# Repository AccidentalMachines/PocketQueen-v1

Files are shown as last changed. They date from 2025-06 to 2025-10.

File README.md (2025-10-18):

# Pocket Queen 1.0

**Pocket Queen** is a modern 3D-printed metronome for drummers, featuring both audible and visual tempo cues. It’s designed to sit on a table or mount anywhere on a drum kit using a standard 1/4-20 clamp.

---

## ⚠️ WARNING — Work in Progress
Pocket Queen v1.0 is still a work in progress.  
The current hardware design **does not include an onboard charging circuit** for the lithium-ion battery.  
To recharge the battery, the unit must be **disassembled and the battery removed** for charging with an **Adafruit Micro-Lipo Charger for LiPoly batteries (USB Type-C)**.  

> Note: The Micro-USB port on the Pocket Queen does **not** recharge the battery — it only provides USB data/power to the Adafruit Circuit Playground Bluefruit board.  This critical design limitation **will be addressed in the next hardware revision.**

---

### Features
- Audible metronome click + LED ring for visual cues  
- Tabletop or clamp-mountable design  
- Compact and rugged — made for drummers, by a drummer  
- 3D-printable enclosure and open files for DIYers  

---

### What's in this repo
- `/STL` – 3D-printable files for the enclosure  
- `/Firmware` – Firmware designed for the Adafruit Circuit Playground Bluefruit
- `/BOM.csv` – Bill of Materials with links  
- `/Instructions.pdf` – Assembly and usage guide  

---

### 🔧 Build Your Own
Want to build Pocket Queen yourself?

- 🛠💾 [Hardware, Firmware, & Assembly Guide](https://github.com/AccidentalMachines/PocketQueen-v1/)
- 📘 [More Info at accidentalmachines.com](https://accidentalmachines.com)

Files are free for personal use.  

---

## License

This project is licensed under the Creative Commons Attribution-NonCommercial 4.0 International License.

You're free to use, remix, and build upon this work for personal or educational use.  
Commercial use is not permitted.

Copyright © 2025 Baret Kilbacak  
Learn more: [https://creativecommons.org/licenses/by-nc/4.0/](https://creativecommons.org/licenses/by-nc/4.0/)

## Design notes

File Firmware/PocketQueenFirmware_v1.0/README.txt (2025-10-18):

Thank you for downloading the Pocket Queen v1.0 firmware!

This Arduino sketch (PocketQueenFirmware_v1.ino) powers the Pocket Queen v1.0 metronome — a modular timing tool for drummers, featuring LED ring cues, click output, and onboard controls. It’s designed to run on the Adafruit Circuit Playground board.

📂 Included Files:
- PocketQueenFirmware_v1.ino — the main firmware sketch
- LEDMatSim.cpp — LED simulation logic
- volume_bitmap.c, swg_bitmap.c, bpm_bitmap.c — icon bitmaps for OLED display

📌 Requirements:
- Adafruit Circuit Playground
- 0.96" OLED I2C Display (128x64)
- 3.7V LiPo battery
- Arduino IDE + Adafruit libraries

🔧 Setup:
1. Open `PocketQueenFirmware_v1.ino` in the Arduino IDE
2. Install required libraries (Adafruit Circuit Playground, Adafruit GFX, SSD1306)
3. Upload the code to your Circuit Playground Bluefruit board
4. Connect to your hardware and start drumming

📎 Full hardware files, build guide, and documentation:
→ https://accidentalmachines.com

Questions? Feedback? Want to share your build?
Contact: ekilbacak [dot] com

Enjoy — and stay on time.

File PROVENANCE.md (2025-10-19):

# Provenance

- **Project:** Pocket Queen v1.0  
- **On-chain proof (Zora):** https://zora.co/coin/base:0x53159797a133b0477d252f8068a53515d0940b79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  
- **Intent:** Authorship timestamping only; not a sales channel.

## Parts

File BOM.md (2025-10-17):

## Bill of Materials – Pocket Queen v1

| Item | Description | Quantity | Source/Link | Notes |
|---|---|---|---|---|
| Circuit Board | Adafruit Circuit Playground Express | 1 | [Link](https://www.adafruit.com/product/3333) | Main controller with LEDs, buttons, and speaker |
| Display | Weewooday 0.96" OLED Module 128x64 I2C | 1 | [Link](https://www.amazon.com/dp/B08N6W9Z3G) | OLED screen for BPM display |
| Battery | Adafruit Lithium Ion Polymer Battery - 3.7V 500mAh | 1 | [Link](https://www.adafruit.com/product/1578) | Powers the CPX via JST connector |
| Main Mounting Insert | Rockler Low-Profile Threaded Insert (#39631) | 1 | [Link](https://www.rockler.com/low-profile-threaded-inserts-select-size) | For mounting to drum kit with 1/4-20 hardware |
| Internal Inserts | M3×8×5mm Threaded Inserts (Ktehloy) | 2 | [Link](https://www.amazon.com/dp/B0CLKDPN65) | Used for internal part fastening |
| Internal Inserts | M2.5×2.5×3.5mm Threaded Inserts | 12 | [Link](https://www.amazon.com/dp/B0CLKDPN65) | Used for smaller structural connections |
| Fasteners | Assorted screws for M2.5 & M3 inserts | Varies | [Link](https://www.amazon.com/dp/B075C6C4YR) | To mate with threaded inserts |
| Power Switch | Chanzon SPDT Mini Micro Slide Switch (SS12F15) | 1 | [Link](https://www.amazon.com/dp/B09R3Y6MMN/) | Used for on/off power control |
| Ring Terminals | TE 160344-2 Ring Terminal, M3, 15-20AWG | 4 | [Link](https://www.digikey.com/en/products/detail/te-connectivity-amp-connectors/160344-2/2285572) | For clean, secure power and signal connections |
| Wiring Kit | Fermerry 20 AWG Silicone Hookup Wire (6 colors, 50ft each) | 1 set | [Link](https://www.amazon.com/dp/B08D6TNJHS) | Flexible tinned copper wire for internal wiring |

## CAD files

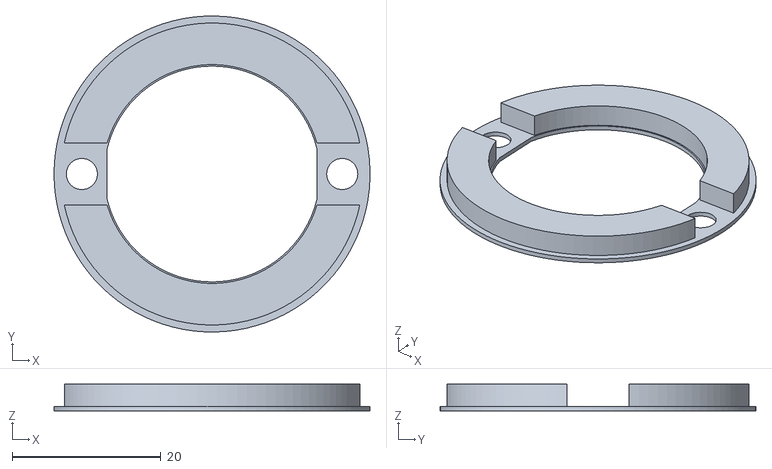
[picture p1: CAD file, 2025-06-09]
STL/PocketQueen-v1-Diffuser.stl
42.5 x 42.6 x 3.60

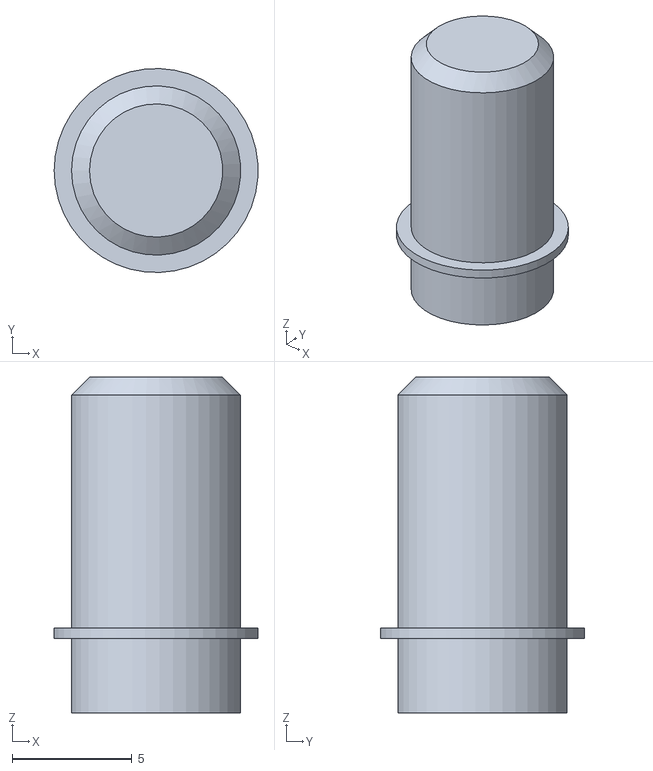
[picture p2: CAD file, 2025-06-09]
STL/PocketQueen-v1-Button.stl
8.49 x 8.49 x 14.0

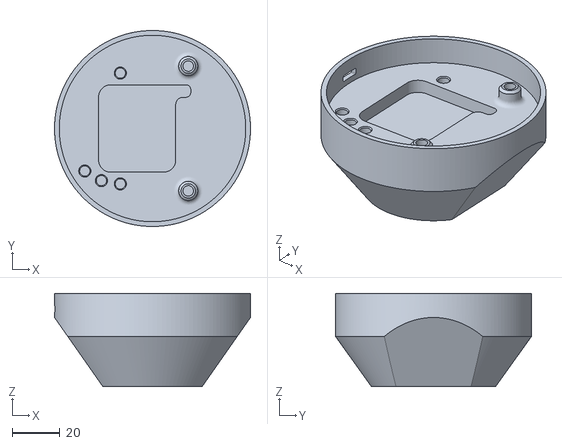
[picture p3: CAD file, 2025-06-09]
STL/PocketQueen-v1-Body.stl
82.0 x 82.0 x 39.0

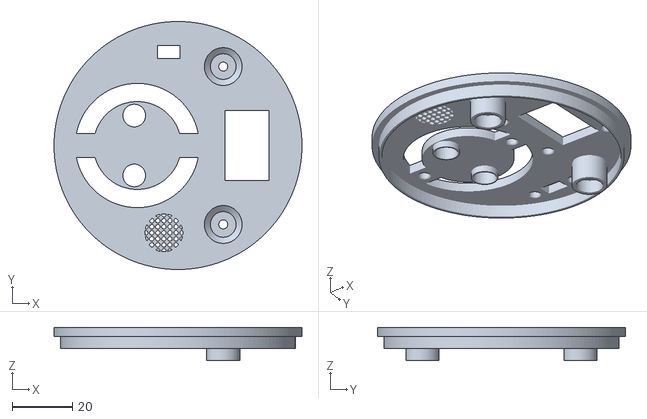
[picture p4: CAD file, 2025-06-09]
STL/PocketQueen-v1-Face-Cover.stl
82.0 x 82.0 x 11.0

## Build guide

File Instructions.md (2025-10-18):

# Pocket Queen v1 – Assembly Instructions

These instructions will walk you through assembling your own Pocket Queen v1 metronome.

---

## 🖨️ Step 1: 3D Printing the Parts

Print the following STL files using your preferred 3D printer (tested on FlashForge Adventurer 4):

- `PocketQueen-v1-Body.stl`
- `PocketQueen-v1-Button.stl`
- `PocketQueen-v1-Diffuser.stl`
- `PocketQueen-v1-Face-Cover.stl`

All files are optimized for standard FDM printing and should work on most hobbyist printers.

---

## 🔩 Step 2: Install Threaded Inserts

Use a soldering iron or insert-setting tool to heat-set the threaded inserts into the appropriate holes in the 3D printed parts:

- M3 and M2.5 inserts go into their designated slots for mounting internal components.

---

## 🔧 Step 3: Wiring and Soldering

1. **Crimp Wires:** Cut and crimp wire leads for connections using ring terminals.
2. **OLED Display:** Solder the wire leads to the pins of the OLED display (I2C interface).
3. **Power Switch:**
   - Cut the positive (red) wire between the battery and its JST connector.
   - Solder the SPDT switch inline to allow power cutoff to the Circuit Playground.

---

## ⚡ Step 4: Final Assembly

1. Mount the **Circuit Playground Bluefruit** inside the main body using screws.
2. Connect the **OLED display** and secure it behind the face cover.
3. Plug in the **battery** via the JST connector.
4. Fit all parts together and secure with screws through the pre-threaded inserts.
5. Snap on the diffuser and press-fit the button into place.

---

## ✅ Final Check

- Flash the firmware from this repo to the Circuit Playground Bluefruit.
- Toggle the switch and confirm LED ring + click sound.
- Secure with clamp or place on table — you're ready to drum.

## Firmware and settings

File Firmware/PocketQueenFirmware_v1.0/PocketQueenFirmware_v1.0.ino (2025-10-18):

// Arduino standard library
#include <Arduino.h>

// Board preprocessor defintions
#ifdef ARDUINO_NRF52840_CIRCUITPLAY
#define ADAFRUIT_CIRCUITPLAYGROUND
#define NRF52_TIMER2
#define AUDIO_CPU
#else // ADAFRUIT_CIRCUITPLAYGROUND_BLUEFRUIT
#ifdef ADAFRUIT_CIRCUITPLAYGROUND_M0
#define ADAFRUIT_CIRCUITPLAYGROUND
#define SAMD_TC4
#define AUDIO_CPU
#else // Not Circuit Playground Express
#if !defined(ARDUINO_NRF52840_CIRCUITPLAY) and !defined(ADAFRUIT_CIRCUITPLAYGROUND_M0)
#define RTOS
#define AUDIO_I2S
#endif 
#endif // ADAFRUIT_CIRCUITPLAYGROUND_M0 
#endif // ADAFRUIT_CIRCUITPLAYGROUND_BLUEFRUIT
#ifdef ADAFRUIT_CIRCUITPLAYGROUND
#define TWO_BUTTONS
#define SPDT_SWITCH
#endif // ADAFRUIT_CIRCUITPLAYGROUND

// Firmware version
#define VERSION F("0.3")

// For USB
#ifdef ARDUINO_NRF52840_CIRCUITPLAY
// #define USB_DISABLE
#define USB_SUSPEND_KEEP_HFCLK
#endif // ARDUINO_NRF52840_CIRCUITPLAY

// For Clock
#ifdef ARDUINO_NRF52840_CIRCUITPLAY
#define ENABLE_HFCLK // Enables high frequency clock when metronome is ticking, required to keep high accuracy when powered by battery
// #define FORCE_HFCLK // Not optimal, but forces high frequency clock every loop to prevent USB suspend event from using lower accuracy internal RC oscillator
#define LFCLK_CALIBRATION_TIME 16 // Calibrate for 4 seconds (16 * 0.25 seconds)
#endif // ARDUINO_NRF52840_CIRCUITPLAY

// For Serial
#ifndef USB_DISABLE
// #define SERIAL_DEBUG
#define SERIAL_DEBUG_WAIT_INIT
#ifdef SERIAL_DEBUG
#define BAUD_RATE 115200
#ifdef ARDUINO_NRF52840_CIRCUITPLAY
#include <Adafruit_TinyUSB.h>
#endif // ARDUINO_NRF52840_CIRCUITPLAY
#endif // SERIAL_DEBUG
#endif // USB_DISABLE

// For Sound
#ifdef RTOS
#include <freertos/FreeRTOS.h>
#include <freertos/task.h>
#endif // RTOS
#ifdef AUDIO_I2S
#include <Audio.h>
#include <SPIFFS.h>
#endif // AUDIO_I2S

// For Display
#ifdef ADAFRUIT_CIRCUITPLAYGROUND
#include <Wire.h>
#else
#include <SPI.h>
#endif // ADAFRUIT_CIRCUITPLAYGROUND
#include <Adafruit_GFX.h>
#include <Adafruit_SSD1306.h>
// Origin offset in pixels
#define ORIGIN_OFFSET_X 0
#define ORIGIN_OFFSET_Y 8
#define ORIGIN_OFFSET_DOT_X ORIGIN_OFFSET_X / 4
#define ORIGIN_OFFSET_DOT_Y ORIGIN_OFFSET_Y / 4
// Dot matrix coordinates
#define TEMPO_DOTS_X 8 + ORIGIN_OFFSET_DOT_X
#define TEMPO_DOTS_Y 0 + ORIGIN_OFFSET_DOT_Y
#define UPPER_TIME_SIGNATURE_X 0 + ORIGIN_OFFSET_DOT_X
#define UPPER_TIME_SIGNATURE_Y 0 + ORIGIN_OFFSET_DOT_Y
#define LOWER_TIME_SIGNATURE_X 0 + ORIGIN_OFFSET_DOT_X
#define LOWER_TIME_SIGNATURE_Y 7 + ORIGIN_OFFSET_DOT_Y
// Bitmaps
#define BPM_BITMAP_X 106 + ORIGIN_OFFSET_X 
#define BPM_BITMAP_Y 16 + ORIGIN_OFFSET_Y
#include "bpm_bitmap.c"
#define SWG_BITMAP_X 104 + ORIGIN_OFFSET_X
#define SWG_BITMAP_Y 16 + ORIGIN_OFFSET_Y
#include "swg_bitmap.c"
#define VOLUME_BITMAP_X 36 + ORIGIN_OFFSET_X
#define VOLUME_BITMAP_Y 43 + ORIGIN_OFFSET_Y
#define VOLUME_DOTS_LENGTH 15
#define VOLUME_DOTS_START_X 10 + ORIGIN_OFFSET_X / 4
#define VOLUME_DOTS_Y 11 + ORIGIN_OFFSET_Y / 4
#include "volume_bitmap.c"

// For NeoPixel
#define NEOPIXEL
#ifdef NEOPIXEL
#include <Adafruit_NeoPixel.h>
#endif //NEOPIXEL

// For Input

// Serial control commands
#ifdef SERIAL_DEBUG
#define SERIAL_CONTROL
#ifdef SERIAL_CONTROL
#define SERIAL_CONTROL_PRESS 'p'
#define SERIAL_CONTROL_LONG_PRESS 'l'
#define SERIAL_CONTROL_TURN_CW 't'
#define SERIAL_CONTROL_TURN_CCW 'r'
#define SERIAL_CONTROL_DEBUG 'd'
#define SERIAL_CONTROL_ETC 'e'
#define SERIAL_CONTROL_SPECIAL 's'
#endif // SERIAL_CONTROL
#endif // SERIAL_DEBUG

// Buttons and switch
#ifdef TWO_BUTTONS
//#define PRESSED_LED // Use builtin LED to indicate short press
#define BUTTON_A 5
#define BUTTON_B 4
#define BUTTON_READ_PERIOD 150UL
#define BUTTON_DOUBLE_PRESS_PERIOD 300UL // Must be multiple of read period for accuracy
#endif // TWO_BUTTONS
#ifdef SPDT_SWITCH
#define SWITCH_A 7
#endif // SPDT_SWITCH

// VCC and temperature debugging
//#define VCC_AND_TEMP_DEBUG

// Rotary encoder
// Pin A, Pin B, Button Pin
//#define ROTARY_ENCODER
#ifdef ROTARY_ENCODER
#include <SimpleRotary.h>
#define ROTARY_A 14
#define ROTARY_B 15
#define ROTARY_BUTTON 2
SimpleRotary rotary(ROTARY_A, ROTARY_B, ROTARY_BUTTON);
#endif // ROTARY_ENCODER

// Input
byte turn;
byte pressed;
byte long_pressed;
// Direction
#define CW 1
#define CCW 2

// LEDs
// #define SETUP_LED // Turns on LED_BUILTIN during initialization to indicate setup time
// #define HFCLK_SRC_LED // Sets LED_BUILTIN to the value of the SRC bit of HFCLKSTAT, indicating clock source
#ifdef NEOPIXEL
#define SEIZURE_PREVENTION
//#define SEIZURE_PREVENTION_TESTING A2
#ifdef ADAFRUIT_CIRCUITPLAYGROUND
#define NEOPIXEL_PIN 8
#define NEOPIXEL_COUNT 10
#define NEOPIXEL_ROTATE
#define NEOPIXEL_COLOR
#define NEOPIXEL_WHITE
#else // Not Circuit Playground board
#define NEOPIXEL_PIN 22
#define NEOPIXEL_COUNT 16
#endif // ADAFRUIT_CIRCUITPLAYGROUND
Adafruit_NeoPixel pixels(NEOPIXEL_COUNT, NEOPIXEL_PIN, NEO_GRB + NEO_KHZ800);
#if defined(NEOPIXEL_COLOR) && defined(NEOPIXEL_WHITE)
#define NEOPIXEL_COLOR_COUNT 6
uint8_t neopixel_color_offset = 0;
#endif // NEOPIXEL_COLOR && NEOPIXEL_WHITE
#endif // NEOPIXEL

// Display
#define OLED
#define LED_MATRIX_SIM
#ifdef OLED
#define SSD1306
#ifdef SSD1306
#define OLED_INIT_DELAY  100
#define OLED_WIDTH 128
#define OLED_HEIGHT 64
#define OLED_ROTATION 0 // 90 degree intervals
#ifdef ADAFRUIT_CIRCUITPLAYGROUND
#define OLED_I2C
#ifdef OLED_I2C
#define OLED_ADDR 0x3C
#define OLED_RESET  -1
#define OLED_SCK    A4
#define OLED_SDA    A5
Adafruit_SSD1306 display(OLED_WIDTH, OLED_HEIGHT, &Wire, OLED_RESET);
#endif // OLED_I2C
#else // ESP32
#define OLED_SPI
#ifdef OLED_SPI
#define OLED_MOSI   23
#define OLED_CLK    18
#define OLED_DC     17
#define OLED_CS     19
#define OLED_RESET  5
Adafruit_SSD1306 display(OLED_WIDTH, OLED_HEIGHT,
    OLED_MOSI, OLED_CLK, OLED_DC, OLED_RESET, OLED_CS);
#endif // OLED_SPI
#endif // ADAFRUIT_CIRCUITPLAYGROUND
#endif // SSD1306
#ifdef LED_MATRIX_SIM
#include "LEDMatSim.cpp"
LEDMatSim ledmatsim(display, 32, 16);

// LED Matrix simulation dot configuration demo
typedef uint8_t bits_t;
bits_t new_dots_wh = 4;
bits_t new_dots[] = {
    0b00000000,
    0b00100000,
    0b00000000,
};

#endif // LED_MATRIX_SIM
#endif // OLED

// Audio constants
#if defined(AUDIO_DAC) || defined(AUDIO_CPU)
#define AUDIO_PIN A0
#define AUDIO_DUR 10
#define AUDIO_FREQ_A4 440.0
#define AUDIO_FREQ_E5 659.25
#define AUDIO_FREQ_A5 880.0
#ifdef ADAFRUIT_CIRCUITPLAYGROUND_M0
#define TONE_RESOLUTION 10
#else
#define TONE_RESOLUTION 8
#endif // ADAFRUIT_CIRCUITPLAYGROUND_M0
#define POWER_OF_TWO(x) (2 ^ x)
#ifdef AUDIO_DAC
#define AUDIO_ANALOG
#else
#define AUDIO_DIGITAL
#endif // AUDIO_DAC
//#define TEST_TONES
#else
#define AUDIO_I2S
#define I2S_LRC 26
#define I2S_DOUT 25
#define I2S_BCLK 27
#endif // AUDIO_DAC

// Audio variables and functions
volatile uint8_t counter = 0;
#if defined(AUDIO_DAC) || defined(AUDIO_CPU)
double audio_freq[] = {AUDIO_FREQ_A4, AUDIO_FREQ_E5, AUDIO_FREQ_A5};
unsigned long previous_tone_time = 0;
#endif // AUDIO_DAC or AUDIO_CPU
#ifdef AUDIO_I2S
Audio audio;
char *audio_files[] = {"/loo.mp3", "/loo_old.mp3" "/hii.mp3"};   
#endif // AUDIO_I2S
#ifdef RTOS
TaskHandle_t audio_task_handle = NULL;
TaskHandle_t audio_task_handle2 = NULL;
#endif // RTOS
#if defined(SAMD_TC4) || defined(NRF52_TIMER2)
volatile unsigned long interval = 1000000UL; // Default to 1 second
#endif // SAMD_TC4 or NRF52_TIMER2

// METRONOME SETTINGS
#define MAX_VOL 100
#define MIN_VOL 0

#define MAX_BEAT 8
#define MIN_BEAT 1

#define MAX_TEMPO 200
#define MIN_TEMPO 20
                
#define MAX_RHYTHM 8
#define MIN_RHYTHM 1

#define MAX_SWING 100
#define MIN_SWING 0

// Metronome settings
bool metronome_on = false;
uint8_t volume_val = 100;
uint8_t beat_val = 4;
uint8_t tempo_val = 120;
uint8_t rhy_val = 1;
uint8_t swing_val = 50;

// Menu constants
#define SELECT_BLINK_TIME 400UL
#define MODIFY_BLINK_TIME 100UL
enum selection // In menu order
{
#ifdef LED_MATRIX_SIM
#define SELECTION_COUNT 5
    SELECT_TEMPO,
    SELECT_SWING,
    SELECT_VOLUME,
    SELECT_RHYTHM,
    SELECT_BEAT
#else // !LED_MATRIX_SIM
#define SELECTION_COUNT 4
    SELECT_VOLUME,
    SELECT_BEAT,
    SELECT_TEMPO,
    SELECT_RHYTHM
#endif
};

// Menu variables
bool select_flag = false;
bool modify_flag = false;
uint8_t select_line = 0;
bool blink_flag = false;
unsigned long last_blink = 0;

#if defined(AUDIO_DAC) || defined(AUDIO_CPU)
// Manual tone generation to su
void volumeTone(uint32_t frequency, uint32_t duration, uint8_t volume)
{
    uint32_t halfPeriod = 1000000UL / frequency / 2;
    #ifdef AUDIO_ANALOG
    volume = map(volume, 0, 100, 0, POWER_OF_TWO(TONE_RESOLUTION));
    #endif // AUDIO_ANALOG

    for (uint32_t i = 0; i < frequency * duration / 1000; i++)
    {
        #ifdef AUDIO_ANALOG
        analogWrite(AUDIO_PIN, volume);
        #endif
        #ifdef AUDIO_DIGITAL
        digitalWrite(AUDIO_PIN, HIGH);
        #endif
        delayMicroseconds(halfPeriod);
        #ifdef AUDIO_ANALOG
        analogWrite(AUDIO_PIN, 0);
        #endif
        #ifdef AUDIO_DIGITAL
        digitalWrite(AUDIO_PIN, LOW);
        #endif
        delayMicroseconds(halfPeriod);
    }
}
#endif // AUDIO_DAC or AUDIO_CPU

#ifdef AUDIO_PWM
void volumeTone(uint32_t frequency, uint32_t duration, uint8_t volume)
{

}
#endif

void playAudio(int audio_index)
{
    #if defined(AUDIO_DAC) || defined(AUDIO_CPU)
    volumeTone(audio_freq[audio_index], AUDIO_DUR, volume_val);
    #endif // AUDIO_DAC or AUDIO_CPU
    previous_tone_time = micros();

    #ifdef AUDIO_I2S
    audio.connecttoFS(SPIFFS, audio_files[audio_index]);
    while (audio.isRunning()) 
    {
        audio.loop();
    }
    #endif // AUDIO_I2S
}

unsigned long calculateTiming()
{
    // Calculate period between metronome ticks based on tempo and rhythm division
    unsigned long period = tempo_val != 0 ? 
        60 * 1000000UL / (tempo_val * rhy_val) : 
        50UL;

    // Adjust period based on swing percentage if not 50%
    return swing_val == 50 ? 
        period : 
        period * (counter % 2 ?
            150 - swing_val : 
            swing_val + 50) 
            / 100.0;
}

void audioTask()
{
    #ifdef RTOS
    TickType_t xLastWakeTime, xFrequency;
    xLastWakeTime = xTaskGetTickCount();
    for (;;)
    #endif // RTOS
    {
        #ifdef RTOS
        vTaskDelayUntil(&xLastWakeTime, xFrequency);
        #endif // RTOS
        #if defined(SAMD_TC4) || defined(NRF52_TIMER2)
        unsigned long timing = calculateTiming();
        #endif // SAMD_TC4 or NRF52_TIMER2
        #ifdef SAMD_TC4
        if(timing != interval) setTC4(timing);
        #else
        #ifdef NRF52_TIMER2
        if(timing != interval) setTIMER2(timing);
        #endif // NRF52_TIMER2
        #endif // SAMD_TC4

        // Play audio
        #if !defined(NRF52_TIMER2) && !defined(SAMD_TC4)
        if(metronome_on)
        #endif // NRF52_TIMER2 && SAMD_TC4
        {
            #ifdef AUDIO_I2S
            audio.setVolume(volume_val);
            #endif

            #if defined(AUDIO_I2S) || defined(AUDIO_DAC) 
            if(
                #ifdef AUDIO_I2S
                audio.isRunning() &&
                #endif // AUDIO_I2S
                #ifdef AUDIO_DAC
                // Check to ensure DAC is done generating audio
                micros() - previous_tone_time >= AUDIO_DUR * 1000
                #endif // AUDIO_DAC
            ) 
            #endif // AUDIO_I2S || AUDIO_DAC
            {
                // Increment and wrap counter
                counter ++;
                counter %= beat_val * rhy_val;

                // Play audio if volume is not 0
                // First beat of measure is sound 2, other beats are sound 1, and subdivisions are sound 0
                if(volume_val)
                    playAudio(
                        counter == 0 ? 2
                        : counter % rhy_val == 0 ? 1
                        : 0);
            }
        }
    }
}

#ifdef SAMD_TC4
void configureTC4()
{
    // Enable shared generic clock for TC4 and TC5
    GCLK->CLKCTRL.reg = GCLK_CLKCTRL_CLKEN |
                        GCLK_CLKCTRL_GEN_GCLK0 |
                        GCLK_CLKCTRL_ID_TC4_TC5;
    while (GCLK->STATUS.bit.SYNCBUSY);
    
    // Reset timer/counter 4
    TC4->COUNT32.CTRLA.reg = TC_CTRLA_SWRST;
    // Wait for syncronization
    while (TC4->COUNT32.STATUS.bit.SYNCBUSY);
    while (TC4->COUNT32.CTRLA.bit.SWRST);

    // Set 32 bit counter and match frequency modes, disable prescaler division, and enables timer counter to start
    TC4->COUNT32.CTRLA.reg |= TC_CTRLA_MODE_COUNT32 |
                              TC_CTRLA_WAVEGEN_MFRQ | TC_CTRLA_PRESCALER_DIV1 | 
                              TC_CTRLA_ENABLE;
    while (TC4->COUNT32.STATUS.bit.SYNCBUSY);

    // Set timer compare capture register
    setTC4(interval);

    // Enable the TC4 interrupt request
    TC4->COUNT32.INTENSET.bit.MC0 = 1;
    // Enable TC4 interrupt
    NVIC_EnableIRQ(TC4_IRQn);
}

void setTC4(unsigned long new_interval) 
{
    interval = new_interval;
    TC4->COUNT32.CC[0].reg = 48UL * interval;
    while (TC4->COUNT32.STATUS.bit.SYNCBUSY);
}

inline void toggleTC4(bool enable)
{
    TC4->COUNT32.CTRLA.bit.ENABLE = enable;
    while(TC4->COUNT32.STATUS.bit.SYNCBUSY);
}

inline void triggerTC4()
{
    TC4->COUNT32.COUNT.reg = TC4->COUNT32.CC[0].reg; 
    while(TC4->COUNT32.STATUS.bit.SYNCBUSY);
}

void TC4_Handler()
{
    // Clear the interrupt flag
    TC4->COUNT32.INTFLAG.bit.MC0 = 1;  
    audioTask();
}
#endif // SAMD_TC4

#ifdef NRF52_TIMER2
void configureTIMER2()
{
    // Set bit size of TIMER2 to 32 bits
    NRF_TIMER2->BITMODE = TIMER_BITMODE_BITMODE_32Bit;
    // Disable prescaler for full clock resolution
    NRF_TIMER2->PRESCALER = 0;
    setTIMER2(interval);
    // Enable interrupts on compare event 0
    NRF_TIMER2->INTENSET = TIMER_INTENSET_COMPARE0_Msk;
    // Clear counter
    NRF_TIMER2->SHORTS = 1UL;
    NVIC_EnableIRQ(TIMER2_IRQn);
    toggleTIMER2(metronome_on);
}

void setTIMER2(uint32_t new_interval)
{
    interval = new_interval;
    NRF_TIMER2->CC[0] = 16UL * new_interval;
}

inline void toggleTIMER2(bool enable)
{
    if(enable)
        NRF_TIMER2->TASKS_START = 1; 
    else
        NRF_TIMER2->TASKS_STOP = 1;
}

inline void triggerTIMER2()
{
    // Run counter capture task to capture compare register 1
    NRF_TIMER2->TASKS_CAPTURE[1] = 1;

    // Set capture compare register 0 to trigger compare event on next clock cycle
    NRF_TIMER2->CC[0] = NRF_TIMER2->CC[1] + 10;

    // Change interval to trigger setTIMER2 on interrupt
    interval = 0;
}

extern "C" void TIMER2_IRQHandler()
{
    if(NRF_TIMER2->EVENTS_COMPARE[0])
    {
        audioTask();
        NRF_TIMER2->EVENTS_COMPARE[0] = 0;
    }
}
#endif

#ifdef ENABLE_HFCLK
inline void calibrateLFCLK()
{
    NRF_CLOCK->CTIV = LFCLK_CALIBRATION_TIME;
    NRF_CLOCK->TASKS_CAL = 1;
    NRF_CLOCK->TASKS_CTSTART = 1;
    while(!NRF_CLOCK->EVENTS_DONE);
    NRF_CLOCK->EVENTS_DONE = 0;
}

inline void startHFCLK()
{
    if(!(NRF_CLOCK->HFCLKSTAT & CLOCK_HFCLKSTAT_SRC_Msk))
    {
        NRF_CLOCK->TASKS_HFCLKSTART = 1;
        while(!NRF_CLOCK->HFCLKRUN);
    }
}

inline void stopHFCLK()
{
    if(NRF_CLOCK->HFCLKSTAT & CLOCK_HFCLKSTAT_SRC_Msk)
        NRF_CLOCK->TASKS_HFCLKSTOP = 1;
}

inline void startLFCLK()
{
    NRF_CLOCK->TASKS_LFCLKSTART = 1;
    while(!NRF_CLOCK->LFCLKRUN);
}
#endif // ENABLE_HFCLK

#ifdef USB_SUSPEND_KEEP_HFCLK
#define RESTART_TRIES 12 // Multiple tries needed for unstable VBUS voltage while unplugging USB causing multiple suspend events
volatile uint8_t hfclk_restart;
extern "C" void tud_suspend_cb(bool remote_wakeup_en)
{
    startHFCLK();
    if(metronome_on)
        hfclk_restart += RESTART_TRIES;
}
#endif // USB_SUSPEND_KEEP_HFCLK

void setup()
{
    pinMode(LED_BUILTIN, OUTPUT);
    #ifdef SETUP_LED
    digitalWrite(LED_BUILTIN, HIGH);
    #endif

    #ifdef SERIAL_DEBUG
    Serial.begin(BAUD_RATE);
    #ifdef SERIAL_DEBUG_WAIT_INIT
    while(!Serial);
    #endif // SERIAL_DEBUG_WAIT_INIT
    Serial.print(F("Soundial Firmware v"));
    Serial.println(VERSION);
    #endif // SERIAL_DEBUG

    #ifdef USB_DISABLE
    NRF_USBD->ENABLE = 0;
    #endif // USB_DISABLE

    #ifdef ENABLE_HFCLK
    startHFCLK();
    calibrateLFCLK();
    #endif // ENABLE_HFCLK

    #ifdef AUDIO_I2S
    // Start SPIFFS
    if(!SPIFFS.begin(true))
    {
        #ifdef SERIAL_DEBUG
        Serial.println(F("SPIFFS Mount Failed"));
        #endif // SERIAL_DEBUG
        for (;;);
    }
    #endif // AUDIO_I2S

    #ifdef OLED
    #ifdef SSD1306
    #ifdef OLED_SPI
    while (!display.begin(SSD1306_SWITCHCAPVCC)) 
    #endif // OLED_SPI
    #ifdef OLED_I2C
    while (!display.begin(SSD1306_SWITCHCAPVCC, OLED_ADDR))
    #endif // OLED_I2C
    {
        #ifdef SERIAL_DEBUG
        Serial.println(F("SSD1306 allocation failed"));
        delay(1000);
        #endif // SERIAL_DEBUG
    }
    #endif // SSD1306
    delay(OLED_INIT_DELAY);
    display.clearDisplay();
    display.print(F("Soundial"));
    display.setCursor(0, 8);
    display.print(F("Firmware v"));
    display.print(VERSION);
    display.setCursor(0, 16);
    display.print(F("Starting..."));
    display.display();
    #endif // OLED

    // NeoPixel
    #ifdef NEOPIXEL
    pixels.begin();
    pixels.fill();
    pixels.setBrightness(20);
    pixels.show();
    #ifdef SEIZURE_PREVENTION_TESTING
    pinMode(SEIZURE_PREVENTION_TESTING, OUTPUT);
    #endif // SEIZURE_PREVENTION_TESTING
    #endif // NEOPIXEL

    // Audio
    #if defined(AUDIO_DAC) || defined(AUDIO_CPU)
    #ifdef AUDIO_ANALOG
    analogWriteResolution(TONE_RESOLUTION);  // Set analog write resolution to 10 bits for DAC
    #endif // AUDIO_ANALOG
    pinMode(AUDIO_PIN, OUTPUT);
    #if defined(AUDIO_CPU)
    digitalWrite(AUDIO_PIN, LOW); // Prevent low hum
    #endif
    //REG_DAC_CTRLA |= DAC_CTRLA_ENABLE;  // Enable DAC
    //pinPeripheral(AUDIO_PIN, PIO_ANALOG) // Set A1 as DAC0 output
    #endif // AUDIO_DAC or AUDIO_CPU
    #ifdef AUDIO_I2S
    audio.setPinout(I2S_BCLK, I2S_LRC, I2S_DOUT, -1);
    audio.setVolumeSteps(170);
    audio.setVolume(volume_val);
    #endif // AUDIO_I2S

    // Test tones
    #ifdef TEST_TONES
    tone(AUDIO_PIN, AUDIO_FREQ_A4, 1000);
    delay(1100);
    volumeTone(AUDIO_FREQ_A4, 1000, volume_val);
    delay(1100);
    #endif // TEST_TONES
    
    #ifdef RTOS
    // Create an audio task on the second core
    xTaskCreatePinnedToCore(audioTask, "AudioTask", 5000, NULL, 1, &audio_task_handle, 1);
    #endif // RTOS

    #ifdef SAMD_TC4
    configureTC4();
    #endif // SAMD_TC4

    #ifdef NRF52_TIMER2
    configureTIMER2();
    #endif // NRF52_TIMER2

    #ifdef TWO_BUTTONS
    pinMode(BUTTON_A, INPUT_PULLDOWN);
    pinMode(BUTTON_B, INPUT_PULLDOWN);
    #endif // TWO_BUTTONS

    #ifdef SPDT_SWITCH
    pinMode(SWITCH_A, INPUT_PULLUP);
    #endif // SPDT_SWITCH

    #ifdef ROTARY_ENCODER
    rotary.setDebounceDelay(5);
    #endif // ROTARY_ENCODER

    #ifdef VCC_AND_TEMP_DEBUG
    initSAADC();
    initTEMP();
    #endif // VCC_AND_TEMP_DEBUG

    #ifdef SETUP_LED
    digitalWrite(LED_BUILTIN, LOW);
    #endif
}

// Adjusts counter for rhythm changes
void adjustCounter(uint8_t previous_rhythm)
{
    // Adjust the subdivision based on the ratio of new rhythm to old rhythm
    uint8_t adjusted_subdivision = counter % previous_rhythm * rhy_val / previous_rhythm;
    
    // Adjust the counter based on the current beat and adjusted subdivision
    counter = counter / previous_rhythm * rhy_val + adjusted_subdivision;
    
    // Wrap counter to valid range
    counter %= (beat_val * rhy_val);
}

#ifdef LED_MATRIX_SIM
void modifySetting(uint8_t& setting, uint8_t min, uint8_t max)
{
    switch(turn)
    {
        case CW:
            if(setting < max)
                setting ++;
            break;
        case CCW:
            if(setting > min)
                setting --;
            break;
    }
}

void modifySettings()
{
    switch(select_line)
    {
        case SELECT_VOLUME:
            modifySetting(volume_val, MIN_VOL, MAX_VOL);
            break;
        case SELECT_BEAT:
            modifySetting(beat_val, MIN_BEAT, MAX_BEAT);
            break;
        case SELECT_TEMPO:
            modifySetting(tempo_val, MIN_TEMPO, MAX_TEMPO);
            break;
        case SELECT_RHYTHM:
        {
            uint8_t previous_rhythm = rhy_val;
            modifySetting(rhy_val, MIN_RHYTHM, MAX_RHYTHM);
            if(previous_rhythm != rhy_val)
                adjustCounter(previous_rhythm);
            break;
        }
        case SELECT_SWING:
            modifySetting(swing_val, MIN_SWING, MAX_SWING);
            break;
    }
}

#else
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
void loop()
{
    #ifdef USB_DISABLE
    NRF_USBD->ENABLE = 0;
    #endif // USB_DISABLE

    #ifdef ENABLE_HFCLK
    if(hfclk_restart)
    {
        startHFCLK();
        hfclk_restart --;
    }
    #endif

    #ifdef FORCE_HFCLK
    startHFCLK();
    #endif // FORCE_HFCLK

    #ifdef HFCLK_SRC_LED
    digitalWrite(LED_BUILTIN, NRF_CLOCK->HFCLKSTAT & CLOCK_HFCLKSTAT_SRC_Msk);
    #endif // HFCLK_SRC_LED

    readInput();

    #ifdef NEOPIXEL
    updateNeoPixels();
    #endif // NEOPIXEL
    
    #ifdef LED_MATRIX_SIM
    updateDisplay();
    #endif // LED_MATRIX_SIM
}

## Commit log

2025-06-09 Added CAD, BOM, Instructions
    [Soundial-v1-Body.stl, Soundial-v1-Button.stl, Soundial-v1-Diffuser.stl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]
2025-10-17 Rename Soundial → Pocket Queen
    Product name updated from 'Soundial' to 'Pocket Queen' for ease of pronunciation
    and a more drum-specific name (pocket is a common term in the drumming community).
    [PocketQueen-v1-Body.stl, PocketQueen-v1-Button.stl, PocketQueen-v1-Diffuser.stl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]
